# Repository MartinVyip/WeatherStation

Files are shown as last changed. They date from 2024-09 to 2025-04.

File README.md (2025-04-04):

# Meteostation Project

A comprehensive weather monitoring system tracking both indoor and outdoor parameters. Capable of storing and graphically respresenting weather data. Performs short-term weather prediction and data restoration in case of emergency power off.

## Project Structure

```plaintext
hardware/
├── BaseStation/
│   ├── Schematic_BaseStation.pdf    # Circuit design for Base Station
│   ├── Drawing_BaseStation.pdf      # Base Station assembly drawing
│   ├── 3Dmodels/
│   │   ├── .sldprt/                 # SolidWorks parts
│   │   └── .stl/                    # Printable 3D files
│   └── PCB/
│       ├── BOM.csv                  # Bill of materials
│       ├── Gerber files             # Manufacturing-ready files
│       └── Layout PDFs              # Top/Bottom views
├── SensModule/
│   ├── Schematic_SensingModule.pdf  # Circuit design for the module
│   ├── Drawing_SensingModule.pdf    # Module assembly drawing
│   ├── 3Dmodels/                    # 3D models of the module
│   └── PCB/                         # PCB designs
include/
├── classes/
│   ├── DataVault.h                  # Data storage and retrieval
│   └── GraphingEngine.h             # Graphical representation of data
├── config/
│   ├── Constants.h                  # IO pins, macros, settings etc.
│   ├── Enums.h                      # Enumeration definitions
│   ├── Globals.h                    # Extern global variables
│   └── Structs.h                    # Data structure definitions
├── core/
│   ├── Backup.h                     # Backup-related key functions
│   ├── Display.h                    # Display-related key functions
│   ├── Peripherals.h                # Hardware initializations
│   ├── Tasks.h                      # FreeRTOS tasks
│   └── Time.h                       # Time and RTC-related key functions
├── rsc/
│   ├── Bitmaps.h                    # Bitmap graphics
│   └── fonts/                       # Custom fonts
└── utils/
    ├── BME280.h                     # Custom BME280 sensor library
    ├── MHZ19B.h                     # Custom MHZ19B sensor library
    ├── SolarWeatherUtils.h          # Solar events and weather estimation
    └── TimeUtils.h                  # Time-related utilities
logos/
├── indoor_indicator.png             # Icon for indoor parameters
├── tal_tech.png                     # Branding
├── connection_icons/                # Icons representing connection status
├── parameter_icons/                 # Icons for weather metrics
└── weather_icons/                   # Icons for weather conditions
src/
├── main.cpp                         # Main station program
├── classes/                         # Class implementations
├── core/                            # Core functions implementation
├── helpers/
│   └── UNIXSender.py                # Script for setting time 
└── utils/                           # Utility implementations
src_module/
└── main.ino                         # Main sensor module program
platformio.ini                       # PlatformIO configuration file
upload.bat                           # Booting script
```

## Station

### **Basic Fucntion**
The central hub of the meteostation, responsible for managing data and interfacing with the sensor module. It retrieves environmental data every two minutes, stores it, and updates a corresponding indicator. Every six minutes, it averages incoming values and saves them to a vault.

Main screen shows:
- **Indoor**: Temperature, humidity, and CO₂ level.
- **Outdoor**: Temperature, humidity, and pressure.
- Time, date, weekday.
- Connection status icon.
- Short-term weather prediction.

### **Time Setting**
The time is automatically adjusted for [DST](https://en.wikipedia.org/wiki/Daylight_saving_time) and can also be precisely set using a Python script that sends [UNIX time](https://en.wikipedia.org/wiki/Unix_time) to the station via UART, requiring a computer connection.

### **Weather Prediction**
Weather prediction is performed based on [least squares interpolation](https://en.wikipedia.org/wiki/Simple_linear_regression) of temperature, humidity, and pressure trends over the past 1.5 hours. The prediction uses a [complementary filter](https://www.sciencedirect.com/topics/computer-science/complementary-filter) to combine trends and determine the weather condition, displayed as a dynamic weather icon (e.g., sunny, stormy).

### **Day/Night Calculation**
**Day and night icons** are adjusted based on sunrise and sunset times, calculated daily using the following method:
1. **Solar Noon Approximation**:  
   The solar noon time is estimated using the cosine function to account for seasonal variations in daylight length based on the current day of the year.

2. **Correction Using the Equation of Time**:  
   The solar noon estimate is refined with the [equation of time](https://en.wikipedia.org/wiki/Equation_of_time), which accounts for the irregularities caused by the Earth's orbital eccentricity and axial tilt.

Using the corrected solar noon as a reference, the station calculates sunrise and sunset times by incorporating the device’s longitude, [GMT offset](https://en.wikipedia.org/wiki/Greenwich_Mean_Time), and the declination of the Sun. This method achieves a precision of a few minutes.

### **Custom Graphics** 
A custom font, designed with the [Adafruit GFX Font Customiser](https://tchapi.github.io/Adafruit-GFX-Font-Customiser/), ensures clarity. All icons were converted to bitmaps using the [Bitmaper application](https://alexgyver.github.io/Bitmaper/).

### **Connection Status Icon**
The connection icon provides real-time feedback:  
- **Bright white**: Connection active.
- **Dim white**: Pending.
- **Off**: Connection lost (pending for 5 minutes).

### **User Interaction**
A PIR sensor detects user presence, automatically turning off the display backlight after a minute of inactivity.

### **Graphical Data Analysis** 
The base station stores 5 days of weather data, allowing users to study metrics graphically. Graphs display daily spans, automatically scaled with maximum and minimum indicators. A rotary encoder enables scrolling through week-long data, switching between day-based and week-based views, and zooming in with a cursor to inspect specific data points. All graph dynamics are rendered with real-time internal graphics calculations, leveraging the STM32F4's [floating-point unit](https://en.wikipedia.org/wiki/Floating-point_unit) for glitch-free performance.

### **Power Loss Recovery**
In case of a power loss, a 0.22F supercapacitor allows data to be backed up to 32kB EEPROM. The station performs periodic raw data backups every hour, saving only a portion of data directly during power loss. Upon restoration, the device fills gaps using the last available value and recalculates time offsets. A hard reset button clears all stored data, while an RTC powered by a 25F supercapacitor ensures accurate timekeeping.

## Sensing Module

### **Basic Function**
The remote sensor module collects outdoor environmental data and transmits it to the base station via a radio connection. The module uses a PCB antenna, while the station features a 3dBi antenna with an SMA connector for enhanced signal strength.

### **Power Sources** 
The module is powered by a combination of a solar panel with a 25F supercapacitor and a 3V lithium battery. The solar panel serves as the primary power source, with the lithium battery as a backup for extreme conditions, such as prolonged snow coverage.

### **Delivering Power**
A single-chip boost converter has been added to step up the voltage from the power sources to a stable 3.6V. This ensures reliable operation even with low input voltage (as low as 400mV) from the solar panel. [Power supply redundancy schematic](https://elentec.narod.ru/Documents/part10/Index0.htm) prioritizes the higher voltage source, allowing the module to operate seamlessly under varying conditions.

### **Low Power Consumption**
The module is exceptionally efficient, consuming just 9.7µA in idle mode (99.5% of the time). This allows the lithium battery to power the module for over two years without solar input.

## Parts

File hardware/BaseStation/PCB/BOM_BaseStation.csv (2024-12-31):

ID | Name | Designator | Footprint | Quantity | Manufacturer Part | Manufacturer | Supplier | Supplier Part | Price
1 | 1N5817W | D3 | SOD-123_L2.8-W1.8-LS3.7-RD | 1 | 1N5817W | TWGMC(台湾迪嘉) | LCSC | C727113 | 0.022
2 | 5.1kΩ | R14,R1,R3 | R0402 | 3 | 0402WGF5101TCE | UNI-ROYAL(厚声) | LCSC | C25905 | 0.001
3 | 100nF | C1,C2,C9,C10,C13,C16,C17,C18 | C0402 | 8 | CL05B104KO5NNNC | SAMSUNG(三星) | LCSC | C1525 | 0.001
4 | 1uF | C3 | C0402 | 1 | CL05A105KA5NQNC | SAMSUNG(三星) | LCSC | C52923 | 0.003
5 | 2.2nF | C4 | C0402 | 1 | 0402B222K500NT | FH(风华) | LCSC | C1531 | 0.001
6 | 15pF | C5,C6 | C0402 | 2 | 0402CG150J500NT | FH(风华) | LCSC | C1548 | 0.001
7 | 2.2uF | C7,C8,C20 | C0402 | 3 | CL05A225MQ5NSNC | SAMSUNG(三星) | LCSC | C12530 | 0.002
8 | 33nF | C11 | C0402 | 1 | CL05B333KB5VPNC | SAMSUNG(三星) | LCSC | C472437 | 0.008
9 | 22pF | C12,C14 | C0402 | 2 | 0402CG220J500NT | FH(风华) | LCSC | C1555 | 0.001
10 | 1.5pF | C15 | C0402 | 1 | GCM1555C1H1R5CA16D | muRata(村田) | LCSC | C126501 | 0.008
11 | 1pF | C21 | C0402 | 1 | GJM1555C1H1R0BB01D | muRata(村田) | LCSC | C76898 | 0.012
12 | 4.7pF | C22 | C0402 | 1 | 0402CG4R7C500NT | FH(风华) | LCSC | C1569 | 0.001
13 | 10nF | C24 | C0402 | 1 | CL05B103KB5NNNC | SAMSUNG(三星) | LCSC | C15195 | 0.001
14 | 1nF | C25 | C0402 | 1 | 0402B102K500NT | FH(风华) | LCSC | C1523 | 0.001
15 | 22uF | C19 | C0603 | 1 | CL10A226MQ8NRNC | SAMSUNG(三星) | LCSC | C59461 | 0.008
16 | 10uF | C27 | C0603 | 1 | CL10A106MA8NRNC | SAMSUNG(三星) | LCSC | C96446 | 0.015
17 | USBLC6-2SC6 | D1 | SOT-23-6_L2.9-W1.6-P0.95-LS2.8-BL | 1 | USBLC6-2SC6 | ST(意法半导体) | LCSC | C7519 | 0.099
18 | BAT20JFILM | D2 | SOD-323_L1.8-W1.3-LS2.5-RD | 1 | BAT20JFILM | ST(意法半导体) | LCSC | C155590 | 0.045
19 | HDR-M-2.54_1x3 | J2 | HDR-M-2.54_1X3 | 1 |  |  | LCSC | C180248 | 0.136
20 | K2-3.6×6.1_SMD | KEY1 | KEY-SMD_2P-L6.2-W3.6-LS8.0 | 1 | K2-1107ST-A4SW-06 |  | LCSC | C118141 | 0.055
21 | HCB4516KF-101T40 | L1 | BEAD-SMD_L4.5-W1.6 | 1 | HCB4516KF-101T40 | TAI-TECH(台庆) | LCSC | C525678 | 0.051
22 | 2.7nH | L2 | L0402 | 1 | SDCL1005C2N7STDF | Sunlord(顺络) | LCSC | C27123 | 0.004
23 | 3.9nH | L3 | L0402 | 1 | SDCL1005C3N9STDF | Sunlord(顺络) | LCSC | C14033 | 0.004
24 | 8.2nH | L4 | L0402 | 1 | SDCL1005C8N2JTDF | Sunlord(顺络) | LCSC | C16208 | 0.003
25 | KT-0603R | LED1,LED3,LED4 | LED0603-RD | 3 | KT-0603R | KENTO | LCSC | C2286 | 0.005
26 | 19-213/Y2C-CQ2R2L/3T(CY) | LED2 | LED0603-RD-YELLOW | 1 | 19-213/Y2C-CQ2R2L/3T(CY) | EVERLIGHT(亿光) | LCSC | C72038 | 0.021
27 | 2.4GHz | NRF24L1 | QFN-20_L4.0-W4.0-P0.50-BL-EP | 1 | NRF24L01P-R | NORDIC | LCSC | C8791 | 1.756
28 | 10kΩ | R2,R6,R8,R9,R13,R19 | R0402 | 6 | 0402WGF1002TCE | UNI-ROYAL(厚声) | LCSC | C25744 | 0.001
29 | 1kΩ | R4,R5 | R0402 | 2 | 0402WGF1001TCE | UNI-ROYAL(厚声) | LCSC | C11702 | 0.001
30 | 470Ω | R7,R10 | R0402 | 2 | 0402WGF4700TCE | UNI-ROYAL(厚声) | LCSC | C25117 | 0.001
31 | 22kΩ | R11 | R0402 | 1 | 0402WGF2202TCE | UNI-ROYAL(厚声) | LCSC | C25768 | 0.001
32 | 1MΩ | R12 | R0402 | 1 | 0402WGF1004TCE | UNI-ROYAL(厚声) | LCSC | C26083 | 0.001
33 | 10Ω | R18 | R0805_NEW | 1 | 0805W8F100JT5E | UNI-ROYAL(厚声) | LCSC | C17415 | 0.001
34 | LD1117S33TR | U1 | SOT-223_L6.5-W3.5-P2.30-LS7.0-BR | 1 | LD1117S33TR | ST(意法半导体) | LCSC | C86781 | 0.139
35 | AT24C256C-SSHL-T | U2 | SOIC-8_L4.9-W3.9-P1.27-LS6.0-BL | 1 | AT24C256C-SSHL-T | MICROCHIP(美国微芯) | LCSC | C6482 | 0.378
36 | STM32F401RET6 | U3 | LQFP-64_L10.0-W10.0-P0.50-LS12.0-BL | 1 | STM32F401RET6 | ST(意法半导体) | LCSC | C116978 | 2.251
37 | FT232RQ | U4 | QFN-32_L5.0-W5.0-P0.50-BL-EP | 1 | FT232RQ-REEL | FTDI(飞特帝亚) | LCSC | C14090 | 5.71
38 | TYPE-C-31-M-12 | USBC1 | USB-C_SMD-TYPE-C-31-M-12 | 1 | TYPE-C-31-M-12 | 韩国韩荣 | LCSC | C165948 | 0.155
39 | 32.768kHz | X1 | FC-135R_L3.2-W1.5 | 1 | Q13FC13500004 | EPSON(爱普生) | LCSC | C32346 | 0.171
40 | 16MHz | X2 | OSC-SMD_4P-L3.2-W2.5-BL | 1 | X322516MLB4SI | YXC(扬兴晶振) | LCSC | C13738 | 0.057
41 | 10uF | C23 | C0402 | 1 | CL05A106MQ5NUNC | SAMSUNG(三星) | LCSC | C15525 | 0.004

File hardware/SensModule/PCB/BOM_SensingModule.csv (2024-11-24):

ID | Name | Footprint | Quantity | Manufacturer Part | Manufacturer | Supplier | Supplier Part | Price
1 | 100uF | CASE-B_3528 | 1 | TAJB107K006RNJ | Kyocera AVX | LCSC | C16133 | 0.141
2 | 10uF | C0402 | 2 | CL05A106MQ5NUNC | SAMSUNG(三星) | LCSC | C15525 | 0.004
3 | 2.2uH | L0603 | 1 | LQM18PN2R2MFRL | muRata(村田) | LCSC | C337910 | 0.071
4 | 56.2kΩ | R0402 | 1 | 0402WGF5622TCE | UNI-ROYAL(厚声) | LCSC | C54968 | 0.001
5 | MAX17220 | UDFN-6_L2.0-W2.0-P0.65-BL | 1 | MAX17220ELT+T | ADI(亚德诺)/MAXIM(美信) | LCSC | C879657 | 1.152
6 | ICSP | HDR-M-2.54_2X3 | 1 |  |  | LCSC | C65114 | 0.03
7 | 1nF | C0402 | 1 | 0402B102K500NT | FH(风华) | LCSC | C1523 | 0.001
8 | 10nF | C0402 | 1 | CL05B103KB5NNNC | SAMSUNG(三星) | LCSC | C15195 | 0.001
9 | 4.7pF | C0402 | 1 | 0402CG4R7C500NT | FH(风华) | LCSC | C1569 | 0.001
10 | 1pF | C0402 | 1 | GJM1555C1H1R0BB01D | muRata(村田) | LCSC | C76898 | 0.012
11 | 100nF | C0402 | 1 | CL05B104KO5NNNC | SAMSUNG(三星) | LCSC | C1525 | 0.001
12 | 1uF | C0402 | 1 | CL05A105KA5NQNC | SAMSUNG(三星) | LCSC | C52923 | 0.003
13 | 2.4GHz | QFN-20_L4.0-W4.0-P0.50-BL-EP | 1 | NRF24L01P-R | NORDIC | LCSC | C8791 | 1.756
14 | ATMEGA328P | TQFP-32_L7.0-W7.0-P0.80-LS9.0-BL | 1 | ATMEGA328P-AU | MICROCHIP(美国微芯) | LCSC | C14877 | 2.139
15 | BME280 | LGA-8_BME280_BL | 1 | BME280 | Bosch(博世) | LCSC | C92489 | 3.697
16 | 16MHz | OSC-SMD_4P-L3.2-W2.5-BL | 1 | X322516MLB4SI | YXC(扬兴晶振) | LCSC | C13738 | 0.057
17 | 1.5pF | C0402 | 1 | GCM1555C1H1R5CA16D | muRata(村田) | LCSC | C126501 | 0.008
18 | 22pF | C0402 | 2 | 0402CG220J500NT | FH(风华) | LCSC | C1555 | 0.001
19 | 2.7nH | L0402 | 1 | SDCL1005C2N7STDF | Sunlord(顺络) | LCSC | C27123 | 0.004
20 | 8.2nH | L0402 | 1 | SDCL1005C8N2JTDF | Sunlord(顺络) | LCSC | C16208 | 0.003
21 | 3.9nH | L0402 | 1 | SDCL1005C3N9STDF | Sunlord(顺络) | LCSC | C14033 | 0.004
22 | 22kΩ | R0402 | 1 | 0402WGF2202TCE | UNI-ROYAL(厚声) | LCSC | C25768 | 0.001
23 | 10kΩ | R0402 | 4 | 0402WGF1002TCE | UNI-ROYAL(厚声) | LCSC | C25744 | 0.001
24 | 1MΩ | R0402 | 1 | 0402WGF1004TCE | UNI-ROYAL(厚声) | LCSC | C26083 | 0.001
25 | 2.2nF | C0402 | 1 | 0402B222K500NT | FH(风华) | LCSC | C1531 | 0.001
26 | 33nF | C0402 | 1 | CL05B333KB5VPNC | SAMSUNG(三星) | LCSC | C472437 | 0.008
27 | BAT20JFILM | SOD-323_L1.8-W1.3-LS2.5-RD | 3 | BAT20JFILM | ST(意法半导体) | LCSC | C155590 | 0.045
28 | KT-0603R | LED0603-RD | 1 | KT-0603R | KENTO | LCSC | C2286 | 0.006
29 | 470Ω | R0402 | 1 | 0402WGF4700TCE | UNI-ROYAL(厚声) | LCSC | C25117 | 0.001
30 | 100Ω | R0402 | 1 | 0402WGF1000TCE | UNI-ROYAL(厚声) | LCSC | C25076 | 0.001

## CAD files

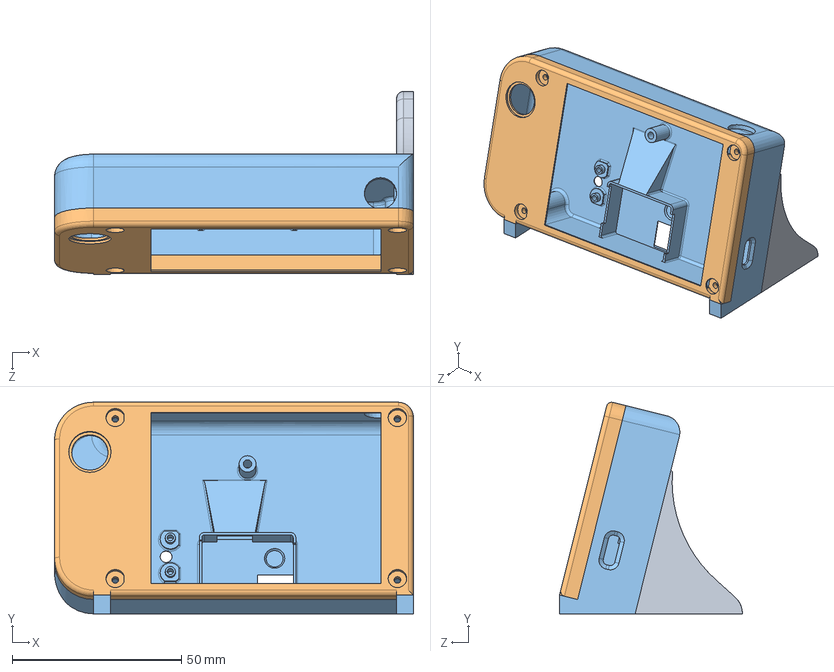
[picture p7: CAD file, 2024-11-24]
hardware/BaseStation/3Dmodels/BaseStation.SLDASM
106.0 x 62.5 x 54.0 mm
BaseStation_Rear
BaseStation_Front
BaseStation_Support

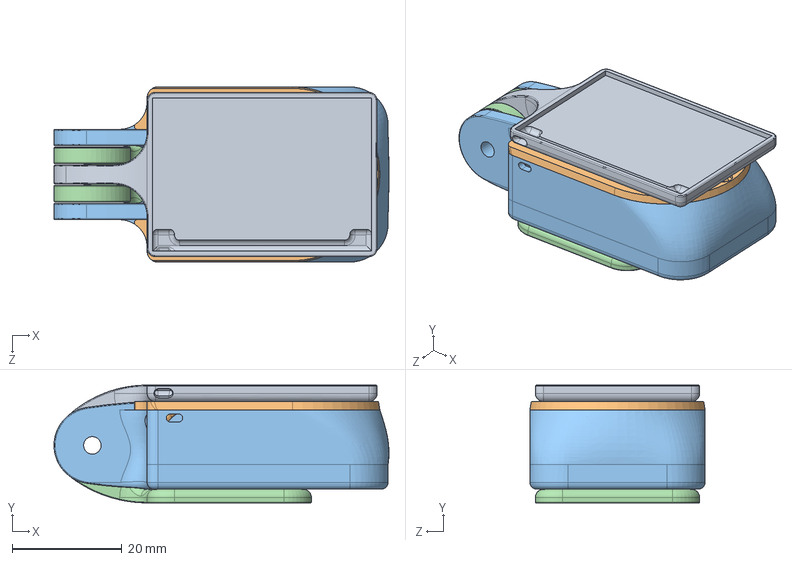
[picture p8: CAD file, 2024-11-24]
hardware/SensModule/3Dmodels/SensModule.SLDASM
61.2 x 21.5 x 32.0 mm
SensModule_Fixture
SensModule_SensorHolder
SensModule_SensorHolderCap
SensModule_SolarHolder

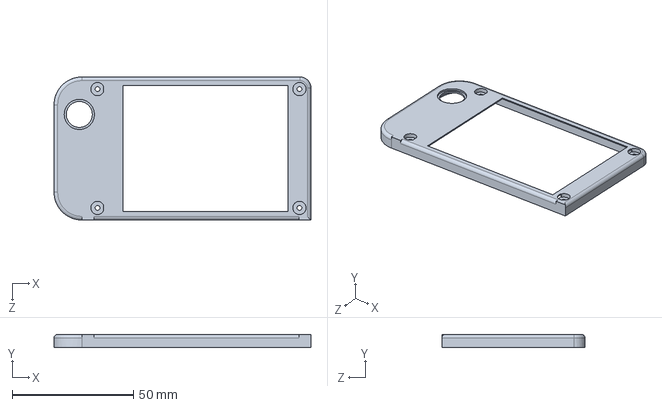
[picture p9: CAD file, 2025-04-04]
hardware/BaseStation/3Dmodels/.sldprt/BaseStation_Front.SLDPRT
106.0 x 5.50 x 59.0 mm

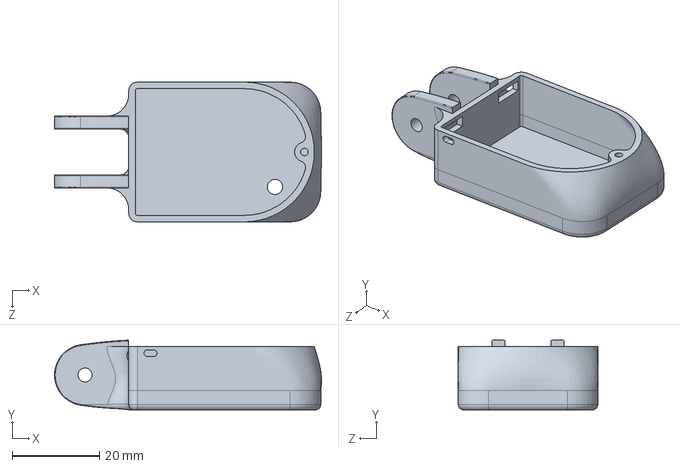
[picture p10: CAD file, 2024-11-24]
hardware/SensModule/3Dmodels/.sldprt/SensModule_SensorHolder.SLDPRT
61.2 x 16.0 x 32.0 mm

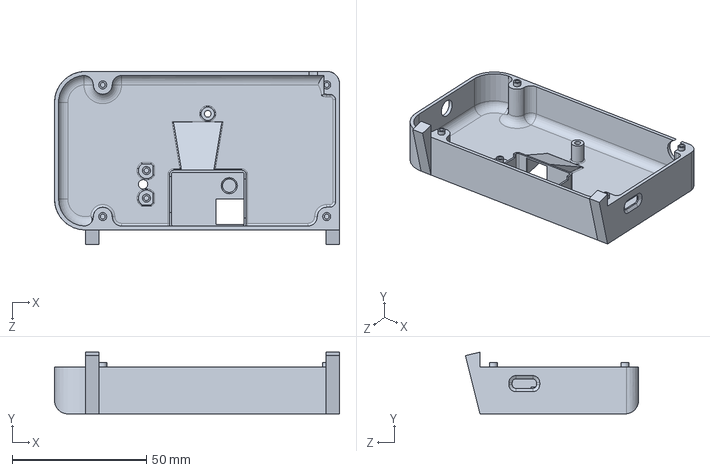
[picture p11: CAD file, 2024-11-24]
hardware/BaseStation/3Dmodels/.sldprt/BaseStation_Rear.SLDPRT
106.0 x 23.0 x 64.4 mm

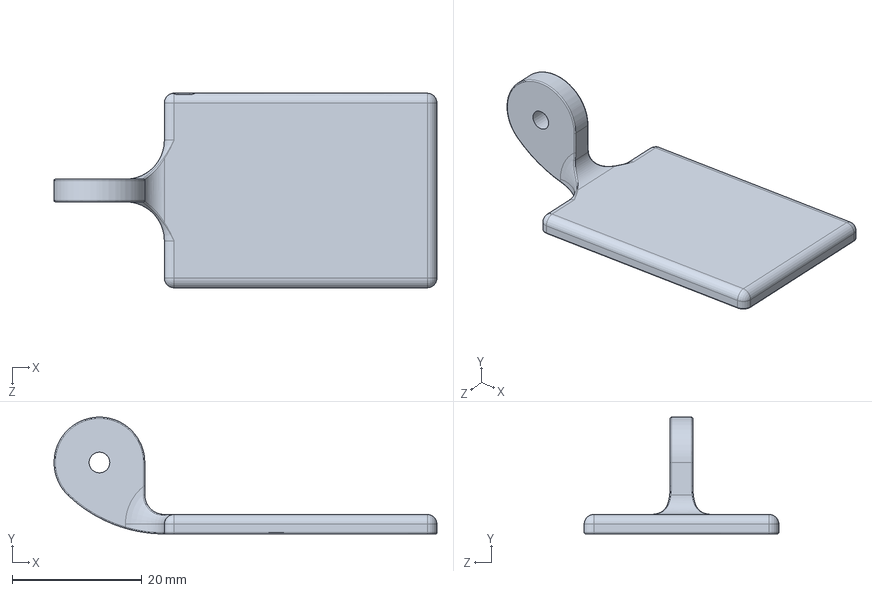
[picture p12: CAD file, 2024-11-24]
hardware/SensModule/3Dmodels/.sldprt/SensModule_SolarHolder.SLDPRT
59.0 x 18.0 x 30.0 mm

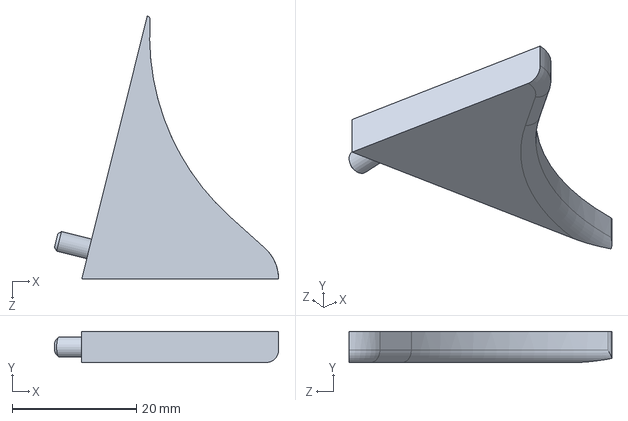
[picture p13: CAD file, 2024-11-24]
hardware/BaseStation/3Dmodels/.sldprt/BaseStation_Support.SLDPRT
36.1 x 5.00 x 42.3 mm

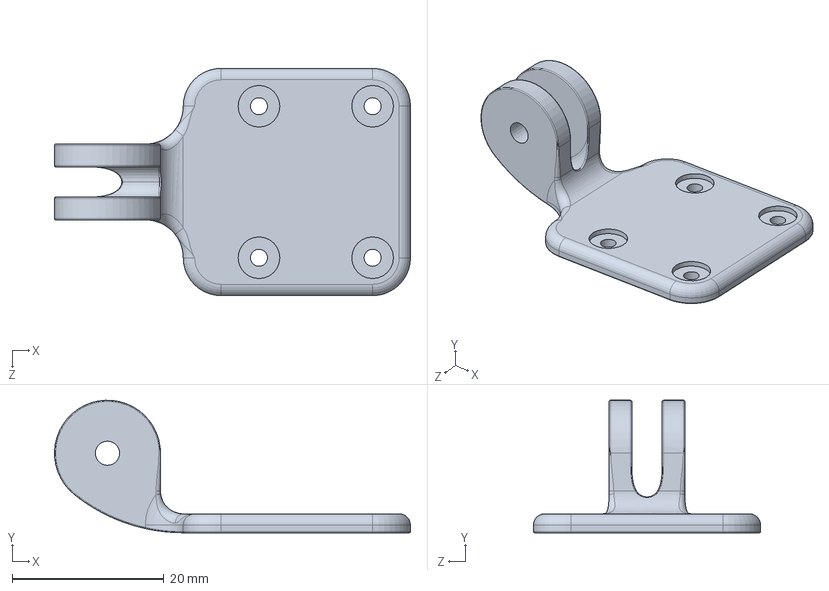
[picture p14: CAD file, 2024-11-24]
hardware/SensModule/3Dmodels/.sldprt/SensModule_Fixture.SLDPRT
47.0 x 17.5 x 30.0 mm

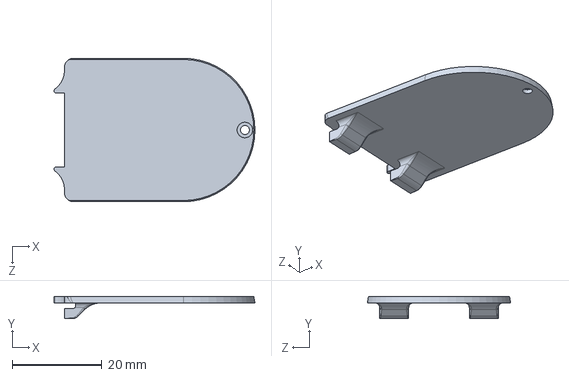
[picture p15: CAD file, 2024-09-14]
hardware/SensModule/3Dmodels/.sldprt/SensModule_SensorHolderCap.SLDPRT
44.8 x 5.00 x 32.0 mm

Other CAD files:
hardware/BaseStation/3Dmodels/.stl/BaseStation_Front.STL
hardware/BaseStation/3Dmodels/.stl/BaseStation_Rear.STL
hardware/BaseStation/3Dmodels/.stl/BaseStation_Support.STL
hardware/BaseStation/3Dmodels/BaseStation.SLDDRW
hardware/SensModule/3Dmodels/.stl/SensModule_Fixture.STL
hardware/SensModule/3Dmodels/.stl/SensModule_SensorHolder.STL
hardware/SensModule/3Dmodels/.stl/SensModule_SensorHolderCap.STL
hardware/SensModule/3Dmodels/.stl/SensModule_SolarHolder.STL
hardware/SensModule/3Dmodels/SensModule.SLDDRW

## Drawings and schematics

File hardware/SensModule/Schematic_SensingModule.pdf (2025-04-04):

## GND

## GND

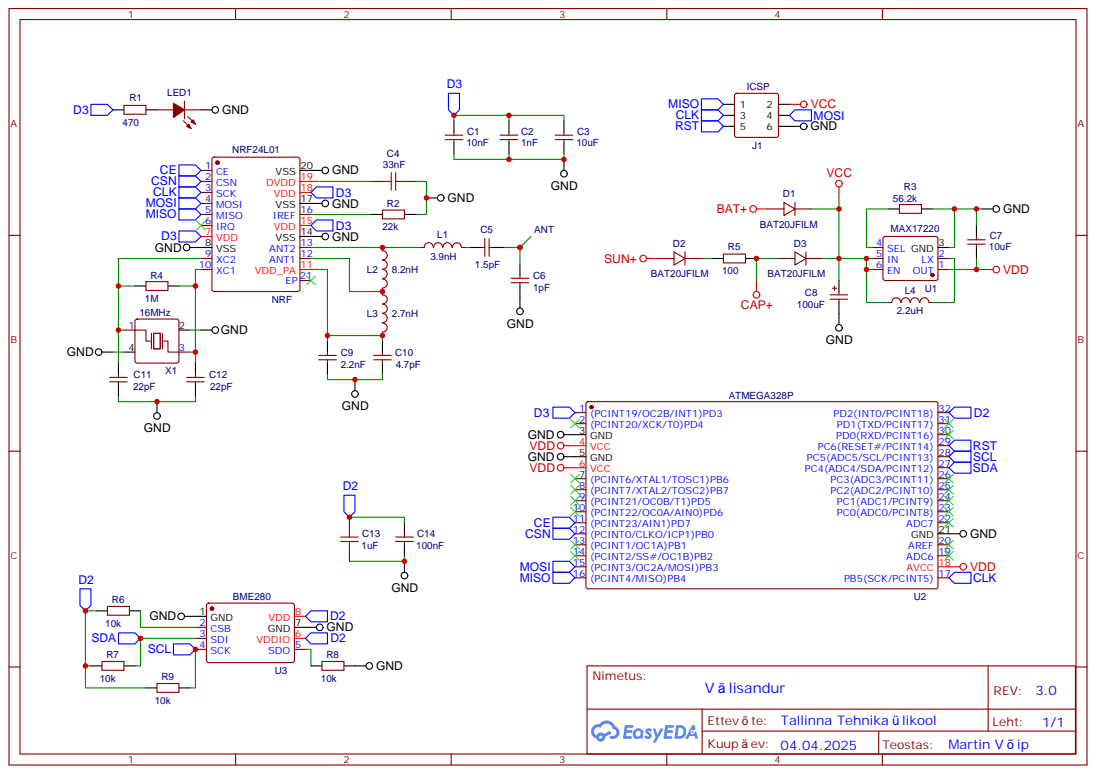
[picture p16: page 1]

Ettev te: Tallinna Tehnika likool
Kuup ev: 04.04.2025

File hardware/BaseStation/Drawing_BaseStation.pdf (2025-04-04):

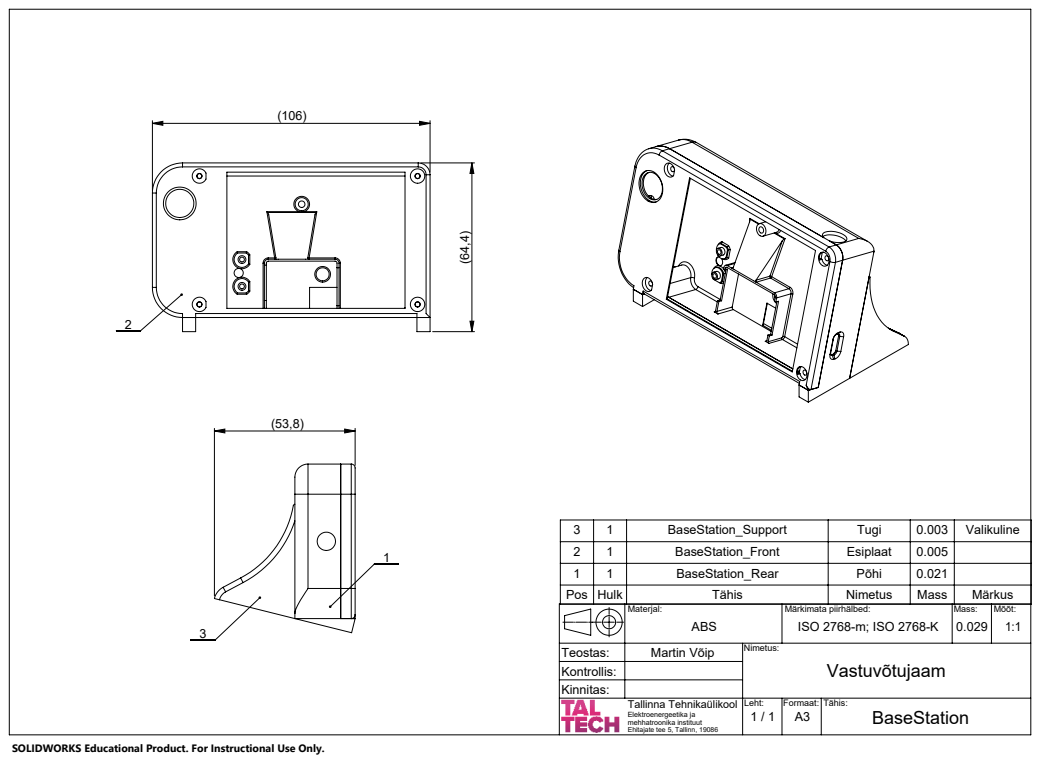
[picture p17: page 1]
Martin Võip; ABS; ISO 2768-m; ISO 2768-K 0.029; Materjal:; Märkimata piirhälbed:; Mass:; Mõõt:; Tallinna Tehnikaülikool; Formaat:

3 | 1 | BaseStation_Support | Tugi | 0.003 | Valikuline
2 | 1 | BaseStation_Front | Esiplaat | 0.005
1 | 1 | BaseStation_Rear | Põhi | 0.021
Pos | Hulk | Tähis | Nimetus | Mass | Märkus

Elektroenergeetika ja
mehhatroonika instituut
Ehitajate tee 5, Tallinn, 19086

SOLIDWORKS Educational Product. For Instructional Use Only.

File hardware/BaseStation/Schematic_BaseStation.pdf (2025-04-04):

+3V3

## L3 VBUS

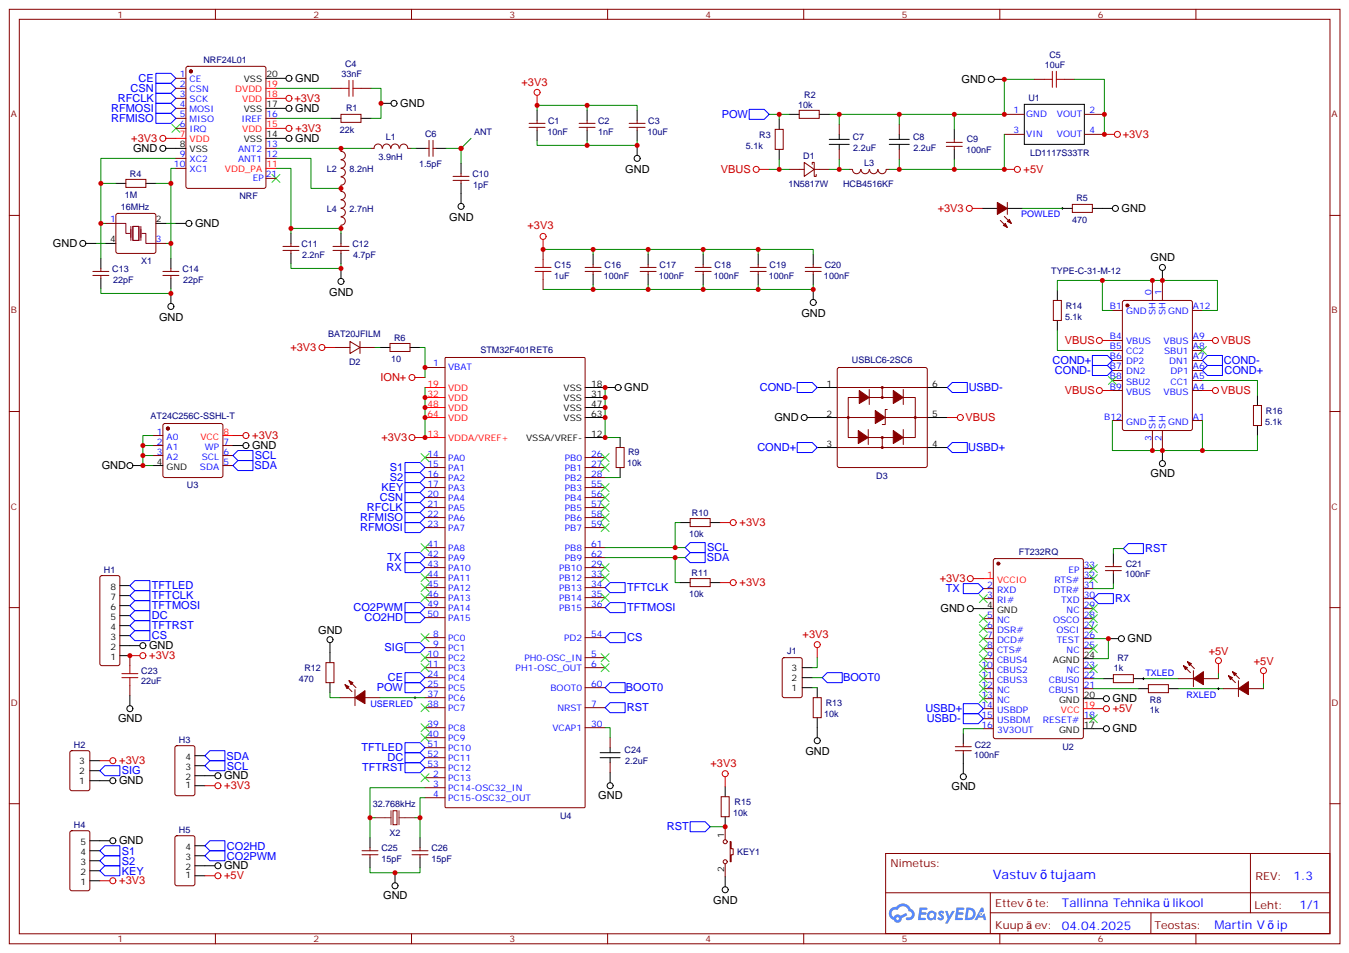
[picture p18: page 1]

Ettev te: Tallinna Tehnika likool
Kuup ev: 04.04.2025

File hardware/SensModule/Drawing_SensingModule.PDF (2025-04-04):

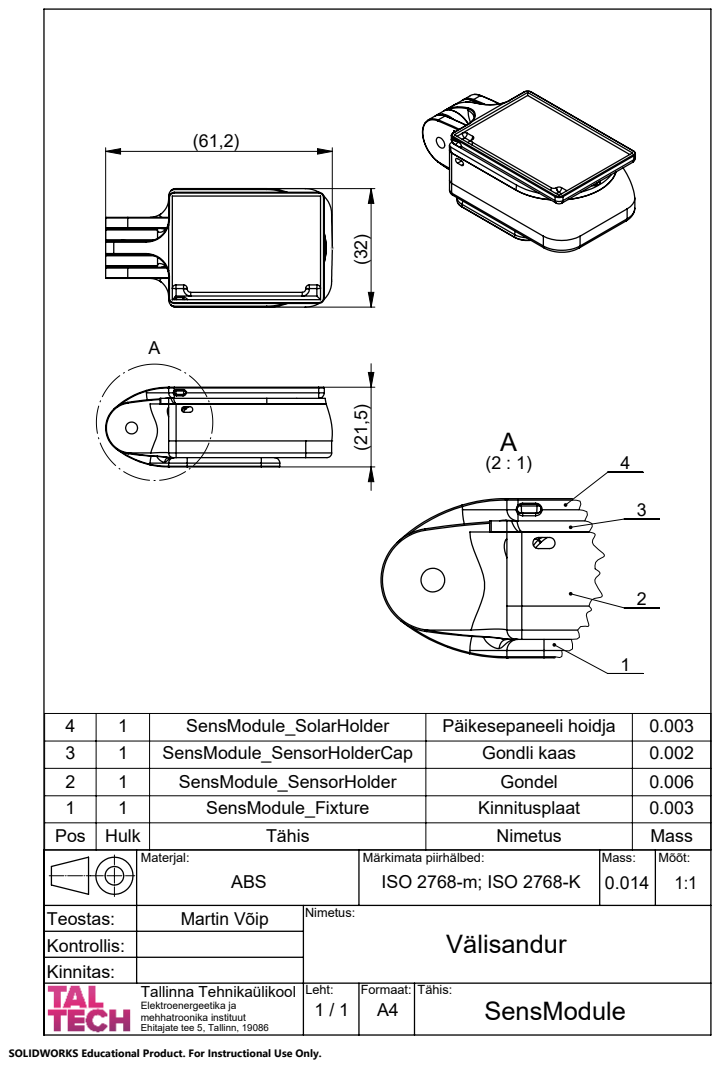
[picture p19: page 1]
ABS; ISO 2768-m; ISO 2768-K 0.014; Materjal:; Märkimata piirhälbed:; Mass:; Mõõt:; Martin Võip; Tallinna Tehnikaülikool; Formaat:

4 | 1 | SensModule_SolarHolder | Päikesepaneeli hoidja | 0.003
3 | 1 | SensModule_SensorHolderCap | Gondli kaas | 0.002
2 | 1 | SensModule_SensorHolder | Gondel | 0.006
1 | 1 | SensModule_Fixture | Kinnitusplaat | 0.003
Pos | Hulk | Tähis | Nimetus | Mass

Elektroenergeetika ja
mehhatroonika instituut
Ehitajate tee 5, Tallinn, 19086

SOLIDWORKS Educational Product. For Instructional Use Only.

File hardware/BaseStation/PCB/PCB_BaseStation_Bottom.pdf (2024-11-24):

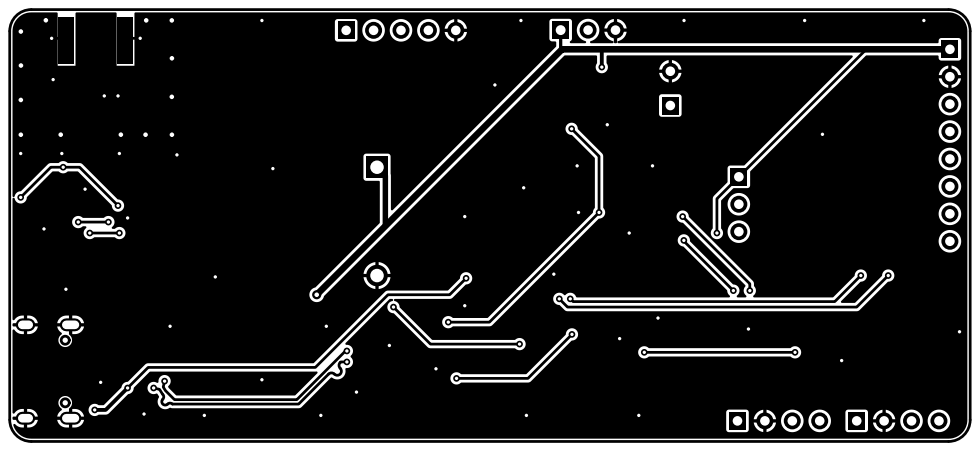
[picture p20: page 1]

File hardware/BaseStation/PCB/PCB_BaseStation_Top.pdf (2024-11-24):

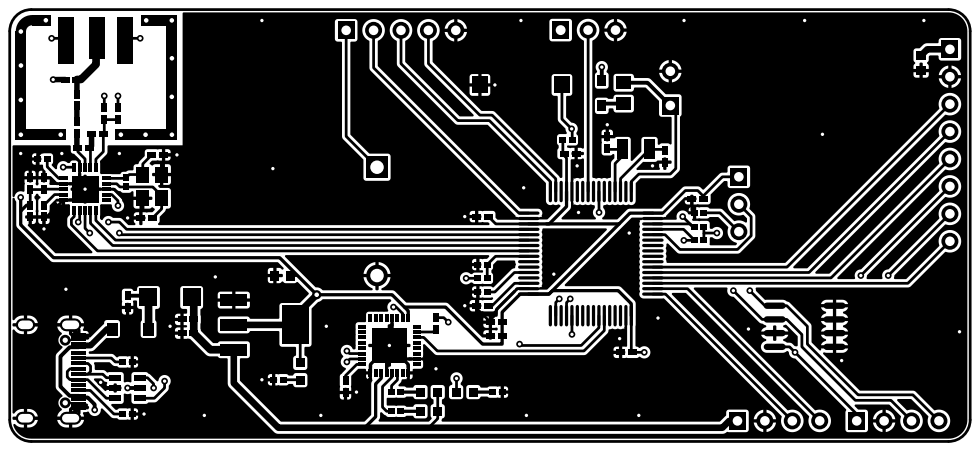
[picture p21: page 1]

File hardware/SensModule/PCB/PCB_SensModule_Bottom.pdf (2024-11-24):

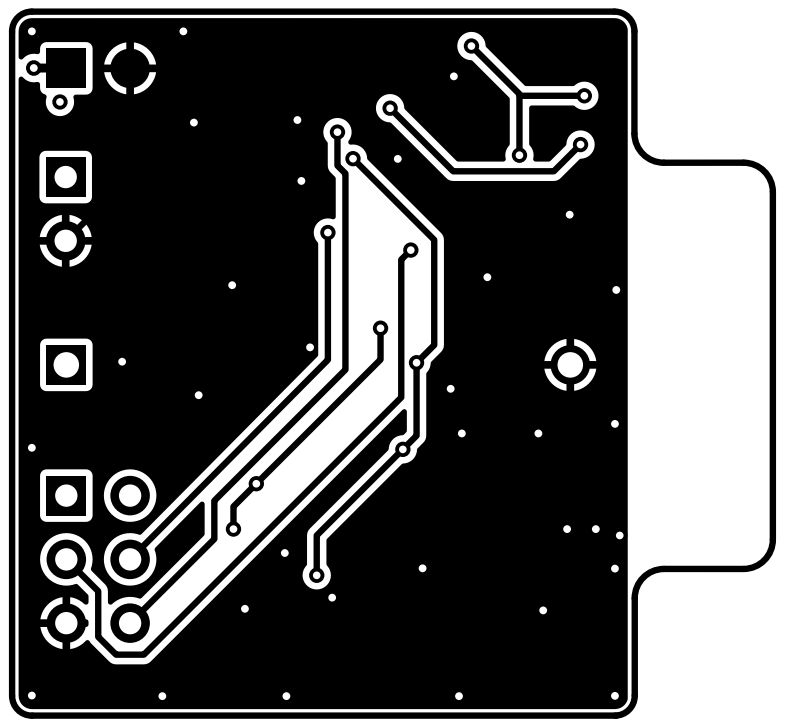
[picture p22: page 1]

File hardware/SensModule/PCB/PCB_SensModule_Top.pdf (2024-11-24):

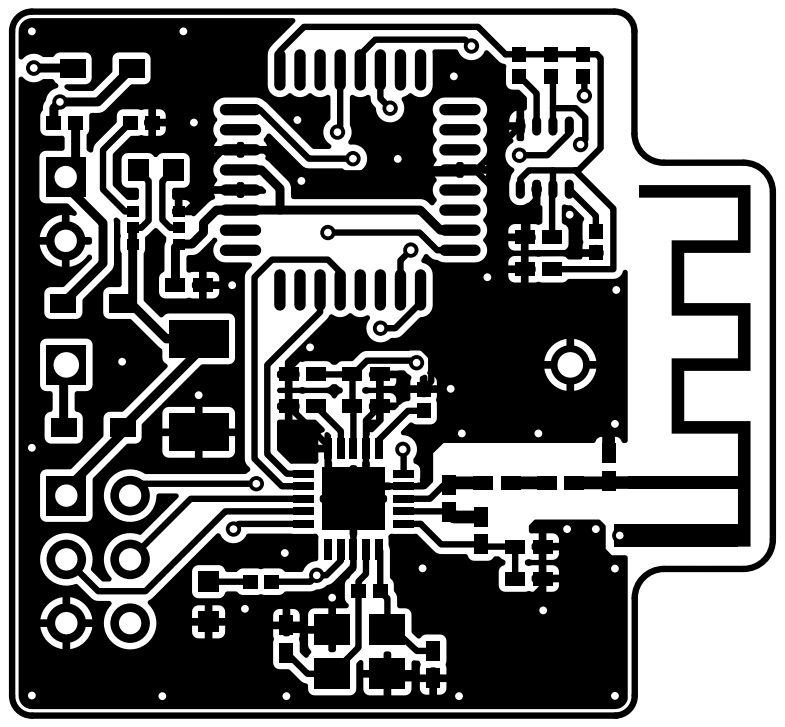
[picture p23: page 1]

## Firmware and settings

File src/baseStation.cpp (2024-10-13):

#include <Arduino.h>
#include <SPI.h>
#include <Wire.h>
#include <SoftwareSerial.h>

#include <rsc/Constants.h>
#include <rsc/Enums&Structs.h>
#include <GraphingBase.h>
#include <GraphingEngine.h>
#include <DataVault.h>

#include <Adafruit_GFX.h>
#include <Adafruit_ILI9341.h>
#include <Adafruit_BME280.h>
#include <RF24.h>
#include <STM32RTC.h>
#include <EncButton.h>
#include <I2C_eeprom.h>
#include <MHZ19.h>

SPIClass tftSPI(TFT_MOSI, TFT_MISO, TFT_CLK);
HardwareSerial UART(RX, TX);
SoftwareSerial MH_UART(MH_RX, MH_TX);
TwoWire I2C(SDA, SCL);

Adafruit_ILI9341 tft(&tftSPI, TFT_DC, TFT_CS, TFT_RESET);
Adafruit_BME280 bme;
EncButton enc(ENC_S1, ENC_S2, ENC_KEY);
RF24 radio(RF_CE, RF_CSN);
MHZ19 co2;
I2C_eeprom eeprom(0x50, &I2C);
STM32RTC& rtc = STM32RTC::getInstance();

inline void tftSetup() {
    pinMode(TFT_LED, OUTPUT);
    digitalWrite(TFT_LED, HIGH);
    tft.begin();
    tft.setRotation(3);
    tft.cp437(true);
}

inline void radioSetup() {
    radio.begin();
    radio.setAutoAck(true);
    radio.setRetries(0, 5);
    radio.setPALevel(RF24_PA_MAX);
    radio.setDataRate(RF24_250KBPS);
    radio.setChannel(0x60);
    radio.openReadingPipe(1, 0x7878787878LL);
    radio.startListening();
}

inline void rtcSetup() {
    rtc.setClockSource(STM32RTC::LSE_CLOCK);
    rtc.begin();
}

inline void co2Setup() {
    MH_UART.begin(9600);
    co2.begin(MH_UART);
    co2.autoCalibration(false);
}

inline void hardwareSetup() {
    delay(500);
    UART.begin(115200);
    I2C.begin();

    co2Setup();
    radioSetup();
    rtcSetup();
    tftSetup();
    eeprom.begin();
    bme.begin(0x76, &I2C);

    enc.setFastTimeout(ENC_FAST_TIME);
}

template <typename input_type>
void updateIndicator(input_type value, const indicator& settings, bool initial) {
    char output[15];

    if constexpr (std::is_arithmetic<input_type>::value) {
        DataVault<input_type>::getCharValue(value, output);
        strcat(output, settings.unit);
    } else {
        strcpy(output, static_cast<const char*>(value));
    }

    tft.setTextColor(settings.color);
    tft.setFont(settings.font);

    if (settings.alignment == "left") {
        tft.setCursor(settings.aln_x, settings.aln_y);
    } else {
        uint16_t width = Graph<input_type>::getTextWidth(output, tft);
        if (settings.alignment == "right") {
            tft.setCursor(settings.aln_x - width, settings.aln_y);
        } else if (settings.alignment == "center") {
            tft.setCursor(settings.aln_x - (width >> 1), settings.aln_y);
        }
    }

    if (!initial) {
        tft.fillRect(settings.bound_x, settings.bound_y,
                     settings.bound_width, settings.bound_height, 0x0000);
    }

    tft.write(output);
}

void updateTime(uint8_t minute) {
    char timestring[5];
    sprintf(timestring, "%02d:%02d", rtc.getHours(), minute);
    updateIndicator(timestring, time_ind, false);
}

void updateDate() {
    char datestring[10];
    siprintf(datestring, "%02d.%02d.%d", rtc.getDay(), rtc.getMonth(), rtc.getYear());
    updateIndicator(datestring, date_ind, false);
}

inline void buildMainScreen() {
    tft.drawRoundRect(-12, 135, 197, 117, 12, SEP_CLR);
    tft.drawRGBBitmap(192, 120, indoor_ind, 120, 40);
    updateIndicator(99.92, out_temp_ind, true);
    updateIndicator(99.92, out_hum_ind, true);
    updateIndicator(999, out_press_ind, true);
    updateIndicator(99.92, in_temp_ind, true);
    updateIndicator(99.92, in_hum_ind, true);
    updateIndicator(9999, co2_rate_ind, true);
    updateTime(rtc.getMinutes());
    updateDate();
    updateIndicator(weekdays[rtc.getWeekDay() - 1], weekday_ind, true);
}

DataVault <float> out_temp(1680);
DataVault <float> out_hum(1680);
DataVault <uint16_t> out_press(1680);
DataVault <float> in_temp(1680);
DataVault <float> in_hum(1680);
DataVault <uint16_t> co2_rate(1680);

GraphBase* plot = nullptr;


void setup() {
    hardwareSetup();

    const int numPoints = 1680;
    const float frequency = 10;

    int day = 0;
    int hour = 0;
    int minute = 0;

    for (int i = 0; i < numPoints; i++) {
        float angle = i * (2 * PI / numPoints);

        // Create unique value for out_temp using a mix of sine wave and sawtooth wave
        float value1 = sin(angle * frequency) * (numPoints - i) / 25 + (fmod(i, 100) / 5.0) - 10;
        out_temp.appendToAverage(value1);
        out_temp.appendToVault(day, hour, minute);

        // out_hum with triangle wave
        value1 = abs(fmod(i * 2, 200) - 100) / 10.0 - 40 + cos(angle * frequency) * 5;
        out_hum.appendToAverage(value1);
        out_hum.appendToVault(day, hour, minute);

        // in_temp with sine + square wave combination
        value1 = (sin(angle * frequency * 2) > 0 ? 1 : -1) * (numPoints - i) / 15 + sin(angle * frequency * 3) * 5 + 85;
        in_temp.appendToAverage(value1);
        in_temp.appendToVault(day, hour, minute);

        // in_hum with a combination of triangle and sine wave
        value1 = (abs(fmod(i * 3, 300) - 150) / 15.0) + sin(angle * frequency / 4) * 5;
        in_hum.appendToAverage(value1);
        in_hum.appendToVault(day, hour, minute);

        // out_press with sawtooth wave + sine wave
        uint16_t value2 = (fmod(i * 1.5, 300) / 1.5) + sin(angle * frequency * 3) * 15 + 990;
        out_press.appendToAverage(value2);
        out_press.appendToVault(day, hour, minute);

        // co2_rate with cosine + step function
        value2 = ((i % 200 > 100) ? 100 : 0) + cos(angle * frequency) * (numPoints - i) + 1950 + i % 50;
        co2_rate.appendToAverage(value2);
        co2_rate.appendToVault(day, hour, minute);
        minute += 6;
        if (minute >= 60) {
            minute = 0;
            hour++;
            if (hour >= 24) {
                hour = 0;
                day++;
                if (day > 7) {
                    day = 0;
                }
            }
        }
    }
}

void loop() {
    static modes curr_mode = SCROLLING;
    static screens curr_screen = MAIN;
    static bool setup = true;
    static uint32_t prev_upd_sens, prev_apd_sens, prev_check;
    static uint8_t curr_min, curr_weekday;

    enc.tick();
    uint32_t curr_time = millis();

    if (curr_time - prev_apd_sens >= APD_PER) {
        uint8_t weekday = rtc.getWeekDay() - 1;
        uint8_t hour = rtc.getHours();
        uint8_t minute = rtc.getMinutes();

        out_temp.appendToVault(weekday, hour, minute);
        out_hum.appendToVault(weekday, hour, minute);
        out_press.appendToVault(weekday, hour, minute);
        in_temp.appendToVault(weekday, hour, minute);
        in_hum.appendToVault(weekday, hour, minute);
        co2_rate.appendToVault(weekday, hour, minute);

        prev_apd_sens = curr_time;
    }

    if (UART.available()) {
        uint8_t time_bytes[4];
        uint32_t unix_time;
        UART.readBytes(time_bytes, sizeof(time_bytes));
        unix_time = (uint32_t)time_bytes[0] << 24 |
                    (uint32_t)time_bytes[1] << 16 |
                    (uint32_t)time_bytes[2] << 8 |
                    (uint32_t)time_bytes[3];
        rtc.setEpoch(unix_time);
    }

    switch (curr_mode) {
        case SCROLLING: {
            if (setup) {
                setup = false;
                tft.fillScreen(0x0000);
                if (curr_screen != MAIN) {
                    switch (curr_screen) {
                        case OUT_TEMP: plot = new Graph<float>(out_temp, tft); break;
                        case OUT_HUM: plot = new Graph<float>(out_hum, tft); break;
                        case OUT_PRESS: plot = new Graph<uint16_t>(out_press, tft); break;
                        case IN_TEMP: plot = new Graph<float>(in_temp, tft); break;
                        case IN_HUM: plot = new Graph<float>(in_hum, tft); break;
                        case CO2_RATE: plot = new Graph<uint16_t>(co2_rate, tft); break;
                    }
                    plot->drawFresh();
                    plot->drawLogos(curr_screen, true);
                    plot->annotate();
                } else {
                    buildMainScreen();
                    prev_check = curr_time;
                }
            }

            if (enc.turn()) {
                if (enc.left()) {
                    curr_screen = (curr_screen > MAIN) ? (screens)(curr_screen - 1) : CO2_RATE;
                } else if (enc.right()) {
                    curr_screen = (curr_screen < CO2_RATE) ? (screens)(curr_screen + 1) : MAIN;
                }
                delete plot;
                plot = nullptr;
                prev_check = curr_time;
                setup = true;
            } else if (enc.click()) {
                if (curr_screen != MAIN) {
                    curr_mode = PANNING;
                    setup = true;
                }
            }
        }
        break;
        case PANNING: {
            if (setup) {
                setup = false;
                plot->drawLocal(false);
                plot->drawLogos(curr_screen, true);
                plot->annotate();
            }

            if (enc.turn()) {
                int8_t step = ((enc.fast()) ? PAN_FAST : PAN_SLOW) * enc.dir();
                plot->dynamicPan(step);
            } else if (enc.click()) {
                curr_mode = CURSOR;
                setup = true;
            } else if (enc.hold()) {
                while(enc.holding());
                curr_mode = SCROLLING;
                plot->drawLocal();
                plot->drawLogos(curr_screen, true);
                plot->annotate();
            }
        }
        break;
        case CURSOR: {
            if (setup) {
                setup = false;
                plot->drawLocal();
                plot->drawLogos(curr_screen, true);
                plot->annotate(false);
                plot->drawCursor(true);
            }

            if (enc.turn()) {
                int8_t step = ((enc.fast()) ? CRSR_FAST : CRSR_SLOW) * enc.dir();
                plot->dynamicCursor(step);
            } else if (enc.click()) {
                curr_mode = PANNING;
                setup = true;
            } else if (enc.hold()) {
                while(enc.holding());
                curr_mode = SCROLLING;
                plot->drawLocal();
                plot->drawLogos(curr_screen, true);
                plot->annotate();
            }
        }
        break;
    }

    if (radio.available()) {
        float received_data[3];
        radio.read(&received_data, sizeof(received_data));
        out_temp.appendToAverage(received_data[0]);
        out_hum.appendToAverage(received_data[1]);
        uint16_t pressure = round(received_data[2] * 0.00750062);
        out_press.appendToAverage(pressure);
        if (curr_screen == MAIN) {
            
        }
    }

    if (curr_time - prev_upd_sens >= UPD_PER) {
        in_temp.appendToAverage(bme.readTemperature());
        in_hum.appendToAverage(bme.readHumidity());
        co2_rate.appendToAverage(co2.getCO2());
        if (curr_screen == MAIN) {
            
        }
        prev_upd_sens = curr_time;
    }

    if (curr_screen == MAIN && curr_time - prev_check >= CHECK_PER) {
        uint8_t minute = rtc.getMinutes();
        if (minute != curr_min) {
            curr_min = minute;
            updateTime(minute);
            uint8_t weekday = rtc.getWeekDay() - 1;
            if (weekday != curr_weekday) {
                curr_weekday = weekday;
                updateDate();
                updateIndicator(weekdays[weekday], weekday_ind, false);
            }
        }
    }
}

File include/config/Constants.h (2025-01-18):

#ifndef Constants_h
#define Constants_h

#include <rsc/fonts/CustomFont10pt.h>
#include <rsc/fonts/CustomFont12pt.h>
#include <rsc/fonts/CustomFont18pt.h>
#include <rsc/fonts/CustomFont24pt.h>
#include <rsc/Bitmaps.h>
#include <config/Enums.h>
#include <config/Structs.h>


// ==================== SETTINGS ====================

#define DATA_PNTS_AMT 1200  // amount of stored data points
#define UPD_PER 60000  // indoor sensors polling period [ms]
#define APD_PER 360000  // period of appending new values to vault [ms]
#define AWAKE_PER 60000  // display backlight timeout [ms]
#define PAN_SLOW 20  // panning speed slow [data points/turn]
#define PAN_FAST 50  // panning speed fast [data points/turn]
#define CRSR_SLOW 1  // cursor speed slow [data points/turn]
#define CRSR_FAST 10  // cursor speed fast [data points/turn]
#define TICK_PER 6  // graph ticks period [hours]

#define BACKSTEP_PER 75  // time period used for weather prediction [min]
#define PRESS_NORM_RANGE 0.01  // highest pressure change [mmHg/min]
#define HUM_NORM_RANGE 0.5  // highest humidity change [%/min]
#define TEMP_NORM_RANGE 0.15  // highest temperature change [°C/min]

#define LONGITUDE 24.75  // station location longitude [degrees]
#define LONGEST_DAY 18  // day length during summer solstice [hours]
#define SHORTEST_DAY 6  // day lenght during winter solstice [hours]
#define GMT_OFFSET 2  // GMT offset, without Daylight Saving Time (DST) [hours]


// ===================== COLORS =====================

#define TEXT_CLR1 0xFE5C  // graph tick data
#define TEXT_CLR2 0xFE5C  // graph weekday
#define TEXT_CLR3 0xFE5C  // cursor data
#define TEXT_CLR4 0xFE5C  // graph annotation data
#define LINK_CLR 0xFD20  // graph annotation arrow
#define AXIS_CLR 0x7BE0  // graph axis
#define TICK_CLR 0x7BE0  // graph tick line
#define SEP_CLR 0x7BE0  // graph weekdays separator line
#define PLOT_CLR 0xC618  // curve
#define CRSR_CLR 0xF800  // cursor


// ===================== IO PINS ====================

#define LED PC6
#define TX PA9
#define RX PA10

#define SDA PB9
#define SCL PB8

#define TFT_MOSI PB15
#define TFT_MISO PB14  // NC
#define TFT_CLK PB13
#define TFT_CS PD2
#define TFT_DC PC11
#define TFT_RESET PC12
#define TFT_LED PC10

#define RF_CE PC4
#define RF_CSN PA4

#define MH_PWM PA14
#define MH_HD PA15

#define PIR PC1
#define POW PC5

#define ENC_KEY PA3
#define ENC_S1 PA1
#define ENC_S2 PA2


// ============== DEVELOPMENT CONSTANTS =============

#define RAW_SOLAR_NOON (60 * (GMT_OFFSET - LONGITUDE / 15))
#define DAYCHANGE_AMP (60 * ((LONGEST_DAY - SHORTEST_DAY) >> 1))

#define PRESS_WEIGHT 0.6
#define HUM_WEIGHT 0.3
#define TEMP_WEIGHT 0.1

#define RECEIVE_THRES 1000
#define PENDING_THRES 300000

#define STORE_PER 3600000
#define POLL_POW_PER 10
#define POLL_ENC_PER 5
#define POLL_BUFS_PER 50
#define POLL_PIR_PER 500
#define POLL_RTC_PER 250
#define SCREEN_UPD_PER 50

#define ENC_FAST_TIME 150
#define APD_PER_S (APD_PER / 60000)
#define BYTES_PER_HOUR ((STORE_PER / APD_PER) << 1)

#define TFT_XMAX 320
#define TFT_YMAX 240
#define L_EDGE 80
#define UP_EDGE 50
#define BT_EDGE 220
#define TICK_LEN 10
#define SEP_LEN 35
#define CRECT_SIDE 16
#define CRECT_HALF (CRECT_SIDE >> 1)

const char degree_celcius[] = {0x7F, 'C', '\0'};
const indicator_config out_temp_ind = {"right", 310, 40, 104, 4, 207, 37, 0xFE5C,
                                       &CustomFont24pt, degree_celcius, false};
const indicator_config out_hum_ind = {"right", 310, 77, 169, 47, 142, 31, 0x7BFF,
                                      &CustomFont18pt, " %", false};
const indicator_config out_press_ind = {"right", 310, 100, 178, 86, 132, 15, 0x2D6A,
                                        &CustomFont10pt, " mmHg", true};
const indicator_config in_temp_ind = {"center", 250, 180, 192, 161, 116, 20, 0xFE5C,
                                      &CustomFont12pt, degree_celcius, false};
const indicator_config in_hum_ind = {"center", 250, 206, 203, 186, 95, 22, 0x7BFF,
                                     &CustomFont12pt, " %", false};
const indicator_config co2_rate_ind = {"center", 250, 230, 186, 216, 129, 15, 0x2D6A,
                                       &CustomFont10pt, " PPM", false};
const indicator_config time_ind = {"center", 90, 178, 5, 144, 172, 35, 0xFE5C,
                                   &CustomFont24pt, "", false};
const indicator_config weekday_ind = {"center", 90, 208, 10, 192, 161, 17, 0xFE5C,
                                      &CustomFont10pt, "", false};
const indicator_config date_ind = {"center", 90, 230, 36, 216, 109, 15, 0xFE5C,
                                   &CustomFont10pt, "", false};

const uint16_t* const summer_graph_icons[] PROGMEM = {
    nullptr,
    high_temp_out, hum_out, press_out,
    high_temp_in, hum_in, co2_in
};

const uint16_t* const winter_graph_icons[] PROGMEM = {
    nullptr,
    low_temp_out, hum_out, press_out,
    low_temp_in, hum_in, co2_in
};
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

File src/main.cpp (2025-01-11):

#include <config/Globals.h>
#include <core/Backup.h>
#include <core/Display.h>
#include <core/Peripherals.h>
#include <core/Time.h>
#include <core/Tasks.h>

SPIClass tftSPI(TFT_MOSI, TFT_MISO, TFT_CLK);
TwoWire I2C(SDA, SCL);
HardwareSerial UART(RX, TX);

Adafruit_ILI9341 tft(&tftSPI, TFT_DC, TFT_CS, TFT_RESET);
BME280 bme(0x76, &I2C);
MHZ19B mhz(MH_PWM, MH_HD);
EncButton enc(ENC_S1, ENC_S2, ENC_KEY);
RF24 radio(RF_CE, RF_CSN);
I2C_eeprom eeprom(0x50, I2C_DEVICESIZE_24LC256, &I2C);
STM32RTC& rtc = STM32RTC::getInstance();

DataVault <float> out_temp(TEMP_NORM_RANGE, eeprom);
DataVault <float> out_hum(HUM_NORM_RANGE, eeprom);
DataVault <float> out_press(PRESS_NORM_RANGE, eeprom);
DataVault <float> in_temp(eeprom);
DataVault <float> in_hum(eeprom);
DataVault <uint16_t> co2_rate(eeprom);

GraphBase* plot = nullptr;
VaultBase* vaults[] = {
    &out_temp, &out_hum, &out_press,
    &in_temp, &in_hum,
    &co2_rate
};

uint16_t last_day_min;
bool backup_ready = false;

state_config state;
SemaphoreHandle_t enc_event, enc_release;
SemaphoreHandle_t state_lock, vault_lock;
TaskHandle_t tasks[NUM_TASKS] = {NULL};


void setup() {
    hardwareSetup();

    if (READ_BACKUP_STATE()) {
        digitalWrite(LED, HIGH);
        tft.fillScreen(0x0000);
        pullBackup();
        digitalWrite(LED, LOW);
    }

    enc_event = xSemaphoreCreateBinary();
    enc_release = xSemaphoreCreateBinary();

    state_lock = xSemaphoreCreateMutex();
    vault_lock = xSemaphoreCreateMutex();

    xTaskCreate(pollPower, "PowerPinPolling", 128, NULL, 4, &tasks[POWER_TASK]);
    xTaskCreate(pollEncoder, "EncoderPolling", 128, NULL, 4, &tasks[ENC_TASK]);
    xTaskCreate(pollPIREvents, "PIRPolling", 128, NULL, 1, &tasks[PIR_TASK]);
    xTaskCreate(pollInputBuffers, "BuffersPolling", 256, NULL, 2, &tasks[BUFFERS_TASK]);
    xTaskCreate(pollRTCEvents, "RTCEvents", 256, NULL, 3, &tasks[RTC_TASK]);

    xTaskCreate(periodicBackup, "PeriodicBackup", 1024, NULL, 2, &tasks[PERIODIC_BACKUP_TASK]);
    xTaskCreate(emergencyBackup, "EmergencyBackup", 1024, NULL, 4, &tasks[EMERGENCY_BACKUP_TASK]);

    xTaskCreate(dataAppend, "DataAppend", 512, NULL, 3, &tasks[APPEND_TASK]);
    xTaskCreate(dataUpdate, "DataUpdate", 512, NULL, 2, &tasks[UPDATE_TASK]);
    xTaskCreate(plotUpdate, "PlotUpdate", 1024, NULL, 4, &tasks[PLOT_TASK]);

    vTaskStartScheduler();
}


void loop() {}

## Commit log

2024-09-14 wrapped into logic
    [BaseStation.SLDASM, BaseStation_Front.SLDPRT, BaseStation_Front.STL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]
2024-11-24 demo release v1.0
    [BOM_BaseStation.csv, BOM_SensingModule.csv, BaseStation.SLDASM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]
2024-12-31 System restructure for FreeRTOS
    [BOM_BaseStation.csv]
2025-01-04 Bug fixes and minor improvements
    [Constants.h, MHZ19B.cpp]
2025-01-11 Improved stability and optimization
    [MHZ19B.cpp, Tasks.cpp]
2025-04-04 Prediction fix and assembly drawings
    [BaseStation.SLDDRW, BaseStation_Front.SLDPRT, SensModule.SLDDRW]
